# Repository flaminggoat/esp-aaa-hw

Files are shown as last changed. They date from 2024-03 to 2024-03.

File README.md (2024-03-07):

# ESP AAA

An AAA battery powered ESP32-C3 board.



# Revisions

* v1.0 - Faulty, Will not start up from an AAA cell, unsuitable boost converter IC used, which requires 1.8V to startup.

# License

Licensed under CERN-OHL-W 
https://cern-ohl.web.cern.ch/

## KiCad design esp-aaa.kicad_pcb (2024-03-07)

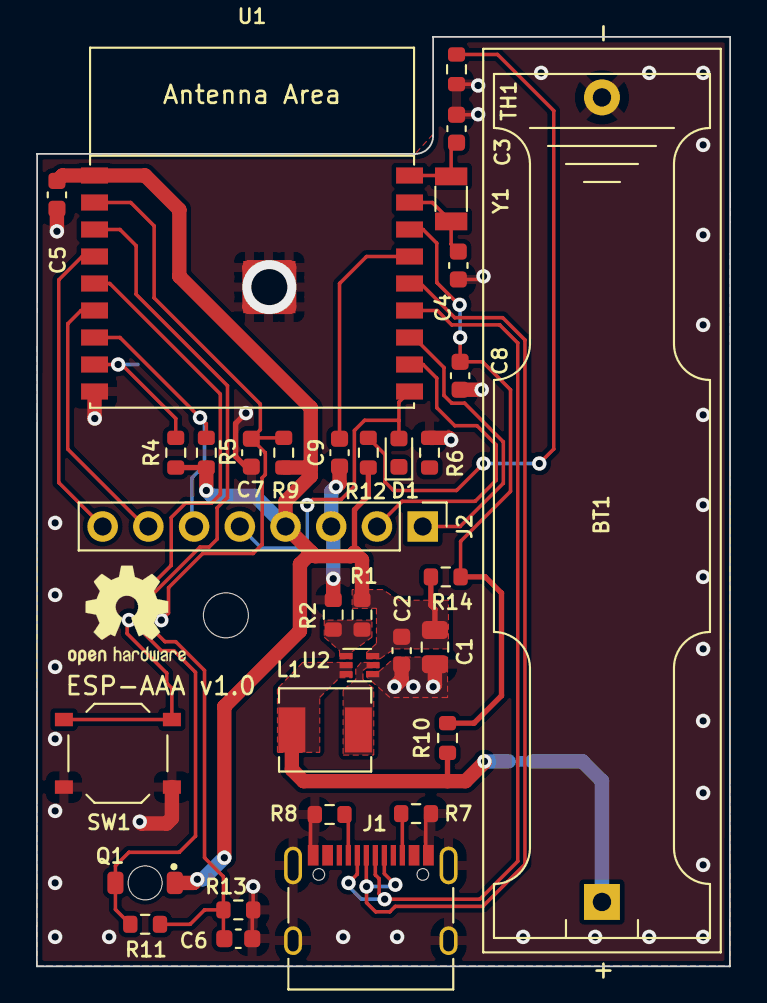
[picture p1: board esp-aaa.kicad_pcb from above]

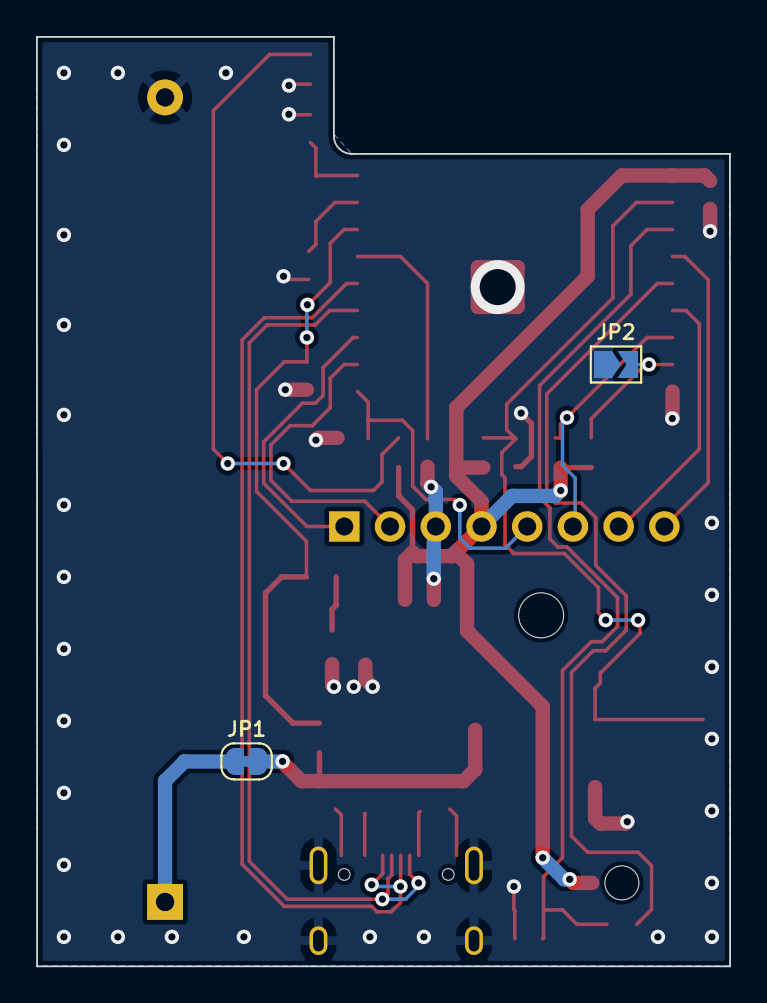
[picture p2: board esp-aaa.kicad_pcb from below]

Board: 2 copper layers, 38.5 x 51.6 mm, 36 parts (2 on the bottom side), 25 nets.

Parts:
BT1: AAA; BatteryHolder_Keystone_2466_1xAAA
C1: 22u; C_0805_2012Metric
C2, C5, C7: 1u; C_0603_1608Metric
C3, C4: 18p; C_0603_1608Metric
C6, C8, C9: 0.1u; C_0603_1608Metric
D1: LED; LED_0603_1608Metric
H1: MountingHole; MountingHole_2.5mm
J1: USB_C_Receptacle_USB2.0; USB_C_Receptacle_XKB_U262-16XN-4BVC11
J2: Conn_01x08_Female; PinHeader_1x08_P2.54mm_Vertical
JP1: SolderJumper_2_Bridged; SolderJumper-2_P1.3mm_Bridged_RoundedPad1.0x1.5mm
JP2: SolderJumper_2_Open; SolderJumper-2_P1.3mm_Open_TrianglePad1.0x1.5mm
L1: 1u; L_Chilisin_BMRA00040415
Q1: IN-S126BTNPT; SML-810TB
R1: 300k; R_0603_1608Metric
R2: 1.3M; R_0603_1608Metric
R4, R5, R9, R10, R14: 10k; R_0603_1608Metric
R6: 1.2k; R_0603_1608Metric
R7, R8: 5.1k; R_0603_1608Metric
R11, R12, R13: 100k; R_0603_1608Metric
SW1: SW_Push; SW_Push_1P1T_XKB_TS-1187A
TH1: TX06F103F3435ER; R_0603_1608Metric
U1: ESP32-C3-WROOM-02
U2: TPS61023; SOT-563
Y1: Q13FC1350000400; Crystal_SMD_3215-2Pin_3.2x1.5mm

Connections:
+3V3: C1.1, C2.1, C5.1, J2.4, Q1.1 (C), R2.2, R4.1, R5.1, R9.2, R12.1, R14.1, U1.1 (3V3), U2.6 (VOUT)
/D+: J1.A6 (D+), J1.B6 (D+), U1.14 (GPIO19/USB_D+)
/D-: J1.A7 (D-), J1.B7 (D-), U1.13 (GPIO18/USB_D-)
/G5: J2.8, U1.4 (GPIO5/ADC2_CH0)
/G7: J2.7, U1.6 (GPIO7)
/G8: J2.6, R5.2, U1.7 (GPIO8)
/G9: JP2.2 (B), R4.2, U1.8 (GPIO9)
/G10: D1.2 (A), J2.5, U1.10 (GPIO10)
/PHOTO_INT: Q1.2 (E), R11.1, U1.5 (GPIO6)
/PHOTO_SENS: C6.1, R11.2, R13.1, U1.3 (GPIO4/ADC1_CH4)
/RXD: J2.2, U1.11 (GPIO20/U0RXD)
/TEMP_SENS: C9.1, R12.2, TH1.1, U1.15 (GPIO3/ADC1_CH3)
/TXD: J2.1, U1.12 (GPIO21/U0TXD)
/VBAT_SENS: C8.1, R10.2, R14.2, U1.16 (GPIO2/ADC1_CH2)
GND: BT1.2 (-), C1.2, C2.2, C3.1, C4.1, C5.2, C6.2, C7.2, C8.2, C9.2, J1.A1 (GND), J1.A12 (GND), J1.B1 (GND), J1.B12 (GND), J1.S1 (SHIELD), J2.3, JP2.1 (A), R1.1, R6.1, R7.2, R8.2, R13.2, SW1.2, TH1.2, U1.9 (GND), U1.19 (GND), U2.4 (GND)
unnamed: BT1.1 (+), JP1.1 (A)
unnamed: D1.1 (K), R6.2
unnamed: J1.A5 (CC1), R8.1
unnamed: J1.B5 (CC2), R7.1
unnamed: JP1.2 (B), L1.1, R10.1, U2.2 (EN), U2.3 (VIN)
unnamed: C7.1, R9.1, SW1.1, U1.2 (EN/CHIP_PU)
unnamed: C3.2, U1.18 (GPIO0/ADC1_CH0/XTAL_32K_P), Y1.1
unnamed: C4.2, U1.17 (GPIO1/ADC1_CH1/XTAL_32K_N), Y1.2
unnamed: R1.2, R2.1, U2.1 (FB)
unnamed: L1.2, U2.5 (SW)
